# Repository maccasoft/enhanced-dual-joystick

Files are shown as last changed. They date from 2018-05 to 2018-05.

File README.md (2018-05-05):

## Enhanced Dual Joystick for RC2014

Add-on board designed for the [RC2014](http://rc2014.co.uk/) computer to provide an enhanced dual joystick port for games and other applications.

The board is based on a Z80 PIO that provide two 8-bit bi-direction parallel ports. Software can configure each port independently to use a standard Atari-compatibile joystick, a NES-compatible gamepad or any
other controller driven by digital I/O lines.

I/O ports can be configured with the on-board dip-switch.

### Schematics

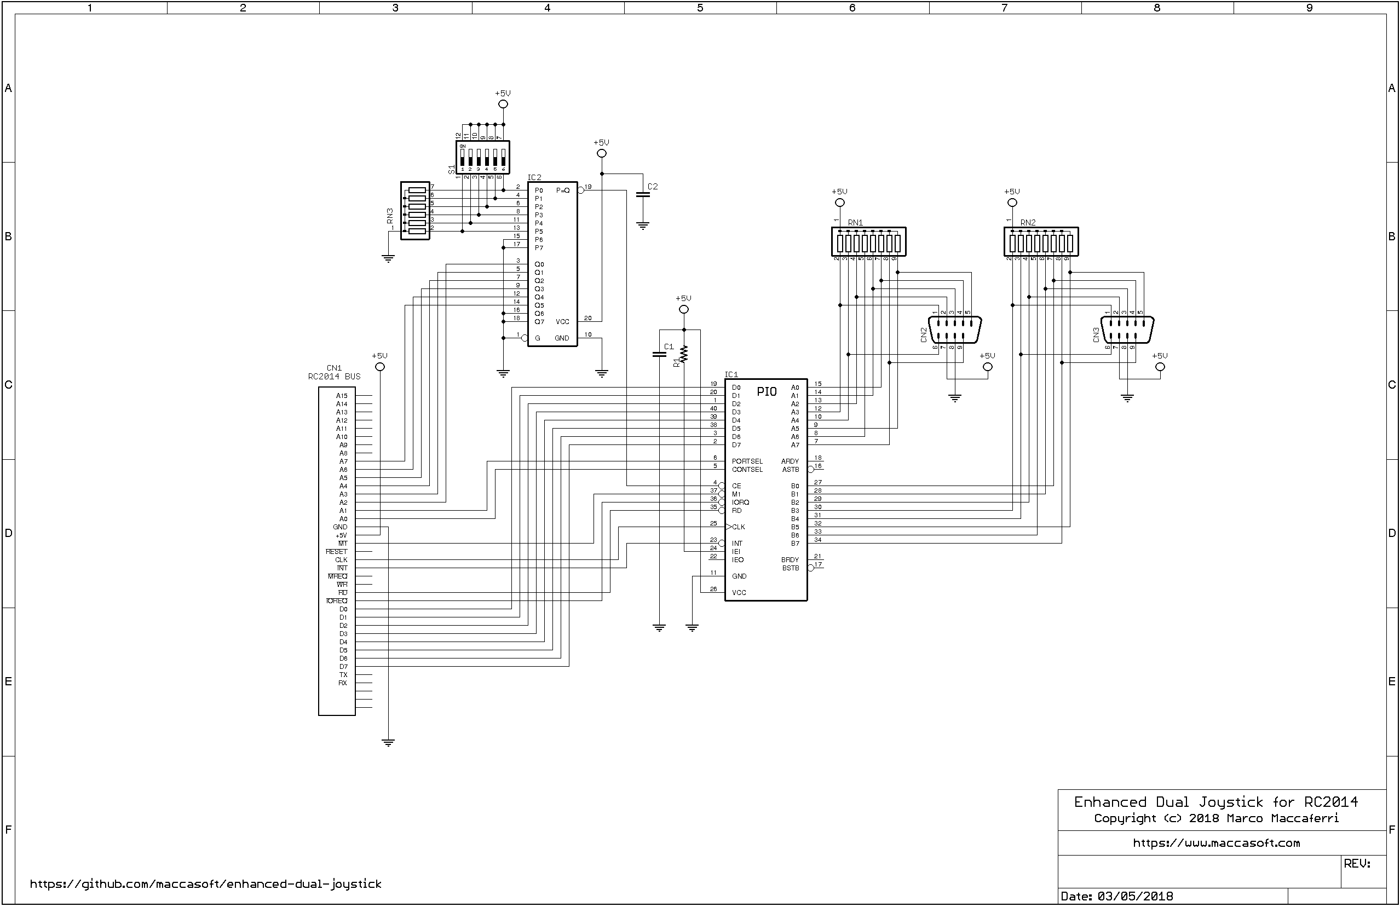
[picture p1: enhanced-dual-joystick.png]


| Parts List  | |
| --- | --- |
| R1 | 10.000 ohm 1/4 watt |
| RN1, RN2 | 10.000 ohm, 9-pin resistor network  |
| RN3 | 10.000 ohm, 7-pin resistor network  |
| C1, C2 | 100.000 pF polyester |
| IC1 | Z84C2010PEG |
| IC2 | CD74HCT688N |
| S1 | DIP-switch |
| CN1 | 40 pin male header, right angle |
| CN2, CN3 | DB9 male connector |

Additionally, a NES-compatible gamepad board is included for those who don't have access to an existing joystick.

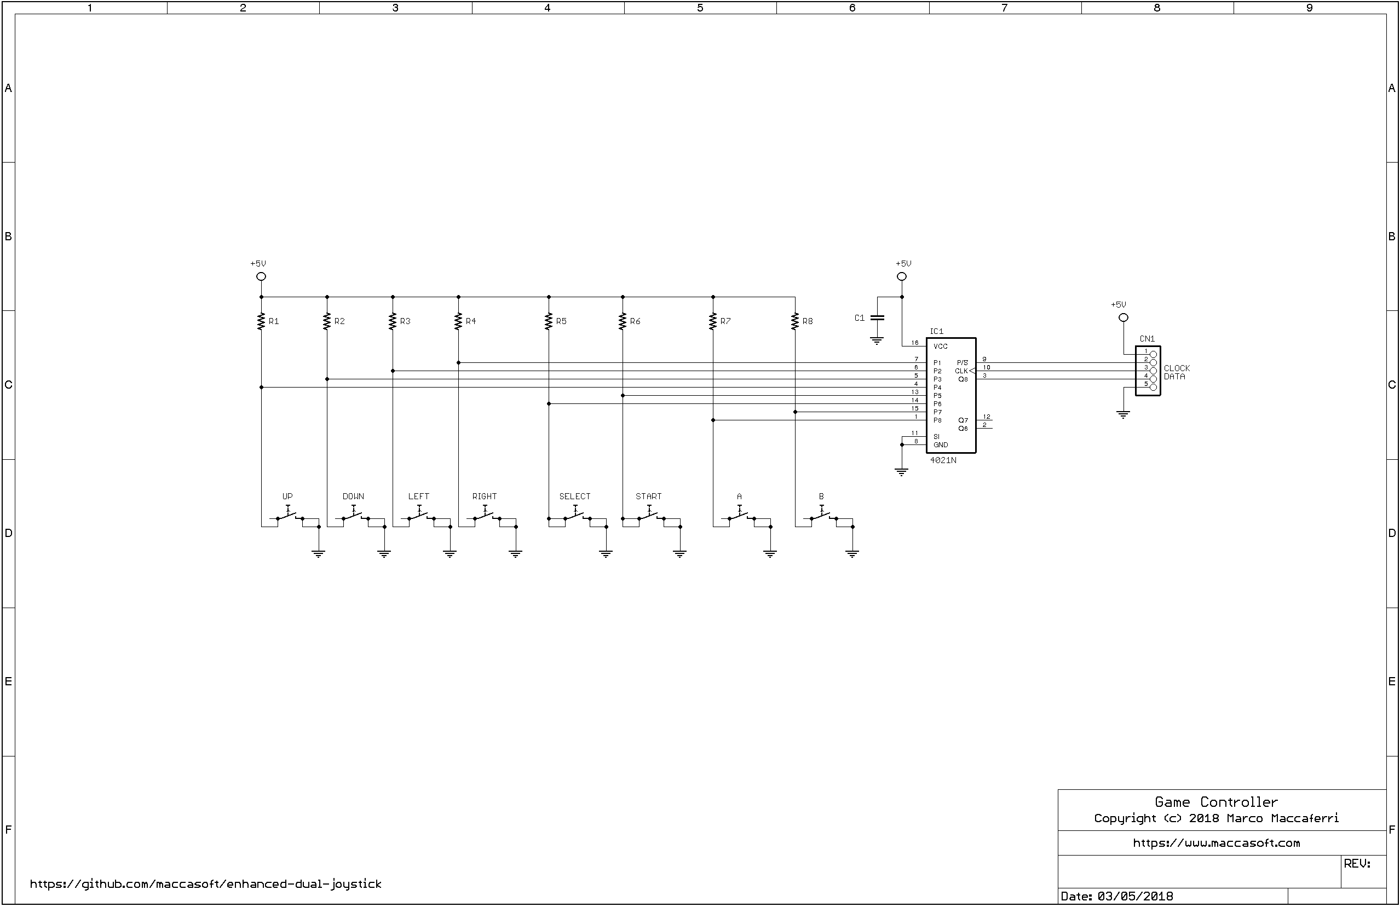
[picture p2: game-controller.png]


| Parts List | |
| --- | --- |
| R1-R8 | 10.000 ohm 1/4 watt |
| C1 | 100.000 pF polyester |
| IC1 | CD4021 |
| UP, DOWN, LEFT, RIGHT | 6x6 mm tact switches |
| SELECT, START, B, A | 6x6 mm tact switches |
| CN1 | 5-pin connector |

### Code Examples

The Z80 PIO must be initialized at startup by configuring both ports in control mode 3 followed by the pin direction settings appropriate for
the game controller type.

**Atari 2600 joystick.**

```
PIO_BASE    .EQU    70H

            ; initialize

            LD      A,0CFH              ; set port A mode 3 (control)
            OUT     (PIO_BASE+1),A
            LD      A,0FFH              ; all pins as input
            OUT     (PIO_BASE+1),A

            LD      A,0CFH              ; set port B mode 3 (control)
            OUT     (PIO_BASE+3),A
            LD      A,0FFH              ; all pins as input
            OUT     (PIO_BASE+3),A

            ; read joystick 1

            IN      A,(PIO_BASE)

            ; read joystick 2

            IN      A,(PIO_BASE+2)
```

**NES gamepad on Joystick 2.**

The code assumes that the gamepad is wired to the DB9 connector as follows: 4=data, 5=load, 6=clk.  

```
PIO_BASE    .EQU    70H

NES_LOAD    .EQU    20H
NES_CLK     .EQU    10H

            ; initialize

            LD      A,0CFH              ; set port A mode 3 (control)
            OUT     (PIO_BASE+1),A
            LD      A,0FFH              ; all pins as input
            OUT     (PIO_BASE+1),A

            LD      A,0CFH              ; set port B mode 3 (control)
            OUT     (PIO_BASE+3),A
            LD      A,~(NES_LOAD|NES_CLK)   ; clock and load pins as output, others as input
            OUT     (PIO_BASE+3),A
            LD      A,0
            OUT     (PIO_BASE+2),A

            ; read joystick 1

            IN      A,(PIO_BASE)

            ; read joystick 2

            LD      C,0

            LD      A,NES_LOAD          ; pulse load pin
            OUT     ((PIO_BASE+2),A
            LD      A,0
            OUT     (PIO_BASE+2),A

            LD      B,8
L1:         IN      A,(PIO_BASE+2)      ; read data from bit 0
            RRA
            RL      C

            LD      A,NES_CLOCK         ; pulse clock
            OUT     (PIO_BASE+2),A
            LD      A,0
            OUT     (PIO_BASE+2),A

            DJNZ    L1

            LD      A,C
```

### Boards

Boards are shared on OSHPark:

[Dual Joystick](https://oshpark.com/shared_projects/1jlMB1r2)  
[Game Controller](https://oshpark.com/shared_projects/LxgxoR9j)  

A [donation](https://www.paypal.me/maccasoft/5eur) to support this and future projects is always welcome!

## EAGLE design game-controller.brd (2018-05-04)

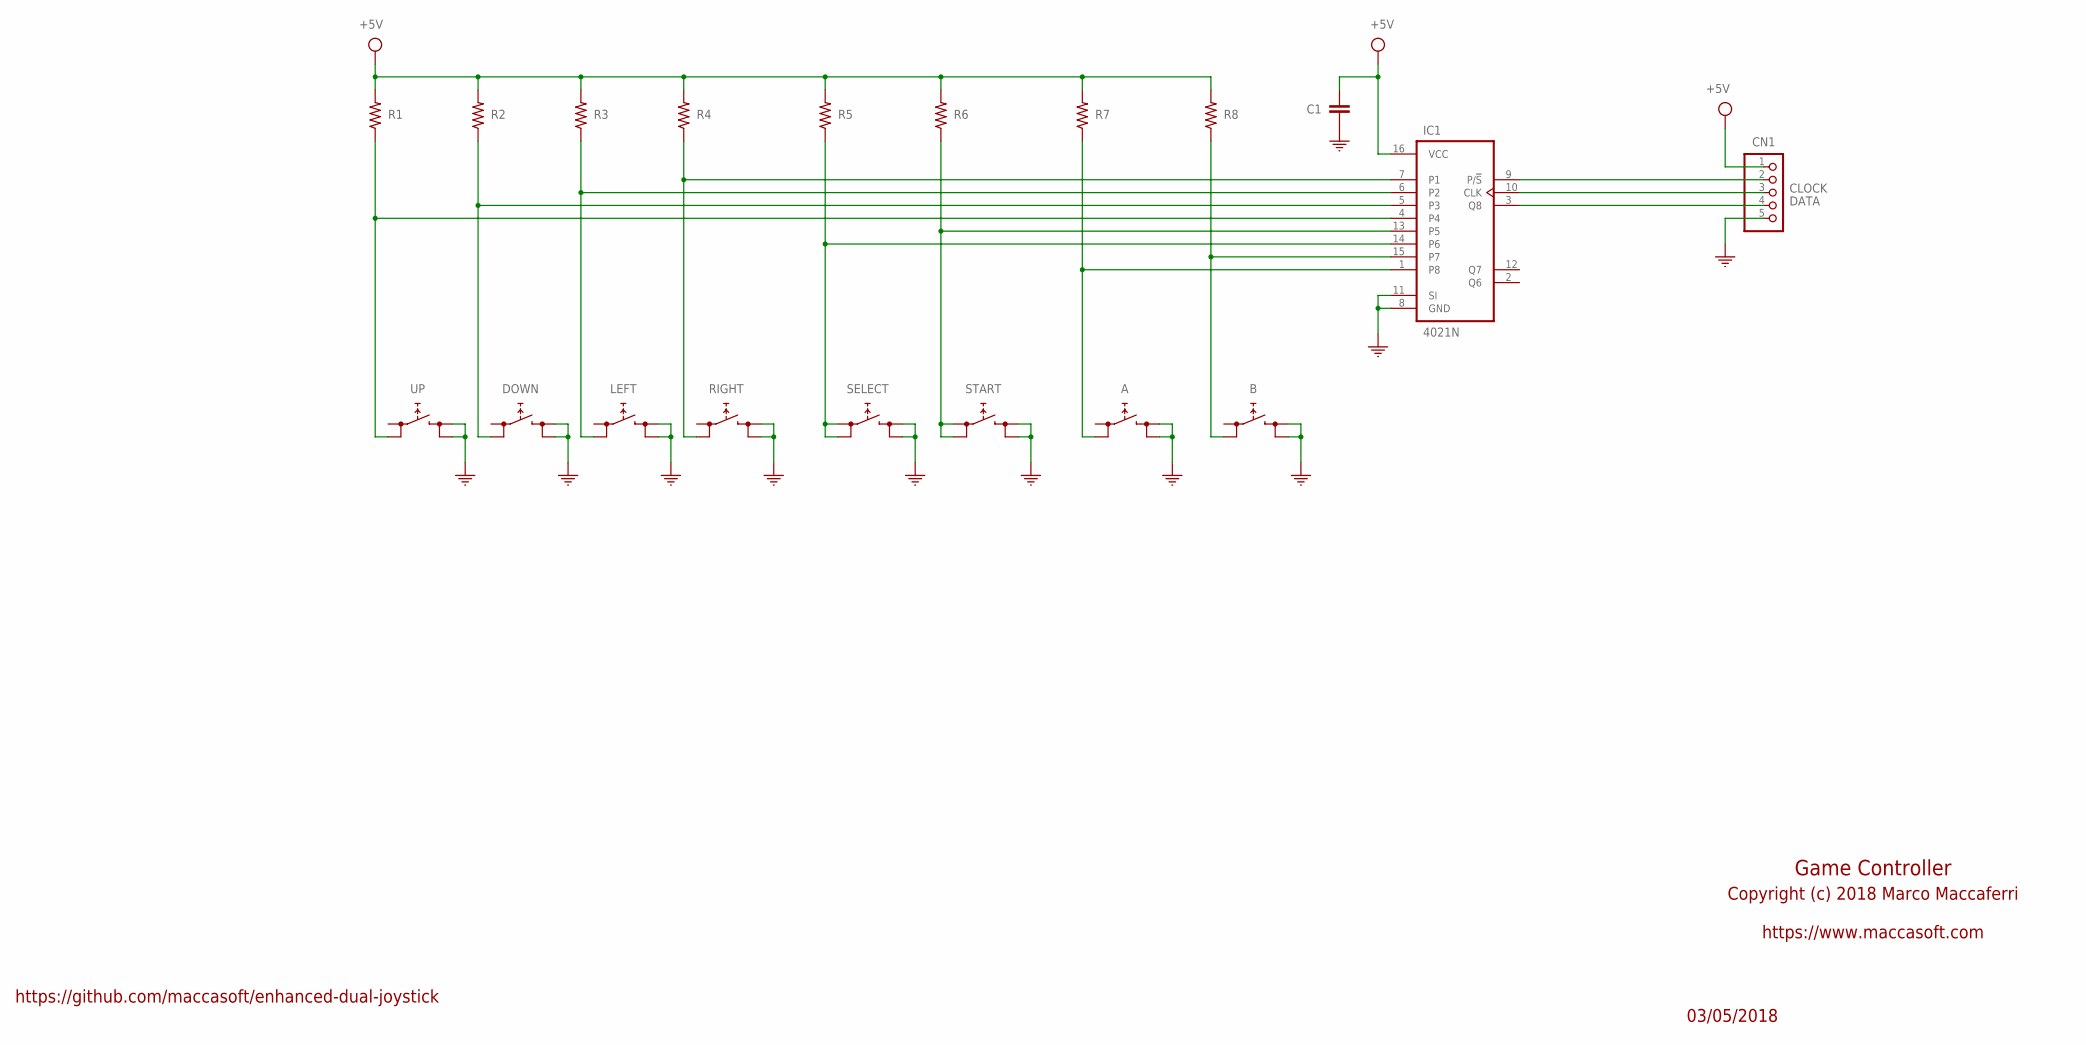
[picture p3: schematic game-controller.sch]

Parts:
A: FSM4JH; TL1105
B: FSM4JH; TL1105
C1: 100nF; C050-025X075; MPN R82EC3100AA70J
CN1: PINHD-1X5; 1X05
DOWN: FSM4JH; TL1105
IC1: 4021N; DIL16
LEFT: FSM4JH; TL1105
R1, R2, R3, R4, R5, R6, R7, R8: 10K; 0207/10; MPN CFR-25JB-52-10K
RIGHT: FSM4JH; TL1105
SELECT: FSM4JH; TL1105
START: FSM4JH; TL1105
UP: FSM4JH; TL1105

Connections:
+3.3V: C1.1, CN1.1, IC1.16 (VCC), R1.2, R2.2, R3.2, R4.2, R5.2, R6.2, R7.2, R8.2
A: A.3 (0), IC1.1 (P8), R7.1
B: B.3 (0), IC1.15 (P7), R8.1
CLOCK: CN1.3, IC1.10 (CLK)
DATA: CN1.4, IC1.3 (Q8)
DOWN: DOWN.3 (0), IC1.5 (P3), R2.1
GND: A.2 (1), A.4 (1), B.2 (1), B.4 (1), C1.2, CN1.5, DOWN.2 (1), DOWN.4 (1), IC1.8 (GND), IC1.11 (SI), LEFT.2 (1), LEFT.4 (1), RIGHT.2 (1), RIGHT.4 (1), SELECT.2 (1), SELECT.4 (1), START.2 (1), START.4 (1), UP.2 (1), UP.4 (1)
LEFT: IC1.6 (P2), LEFT.3 (0), R3.1
unnamed: CN1.2, IC1.9 (P/!S)
RIGHT: IC1.7 (P1), R4.1, RIGHT.3 (0)
SELECT: IC1.14 (P6), R5.1, SELECT.1 (0), SELECT.3 (0)
START: IC1.13 (P5), R6.1, START.1 (0), START.3 (0)
UP: IC1.4, R1.1, UP.3 (0)

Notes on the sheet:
Game Controller
03/05/2018
Copyright (c) 2018 Marco Maccaferri
https://github.com/maccasoft/enhanced-dual-joystick
https://www.maccasoft.com

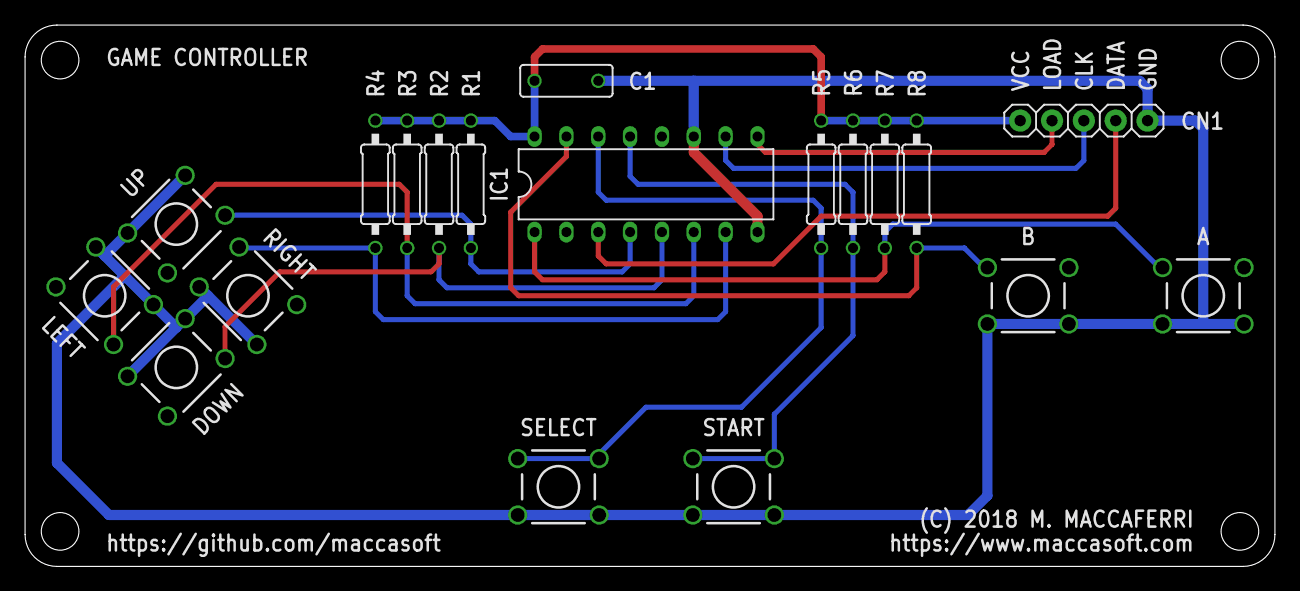
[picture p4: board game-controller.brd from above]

Board: 2 copper layers, 99.7 x 43.2 mm, 19 parts (0 on the bottom side), 13 nets.

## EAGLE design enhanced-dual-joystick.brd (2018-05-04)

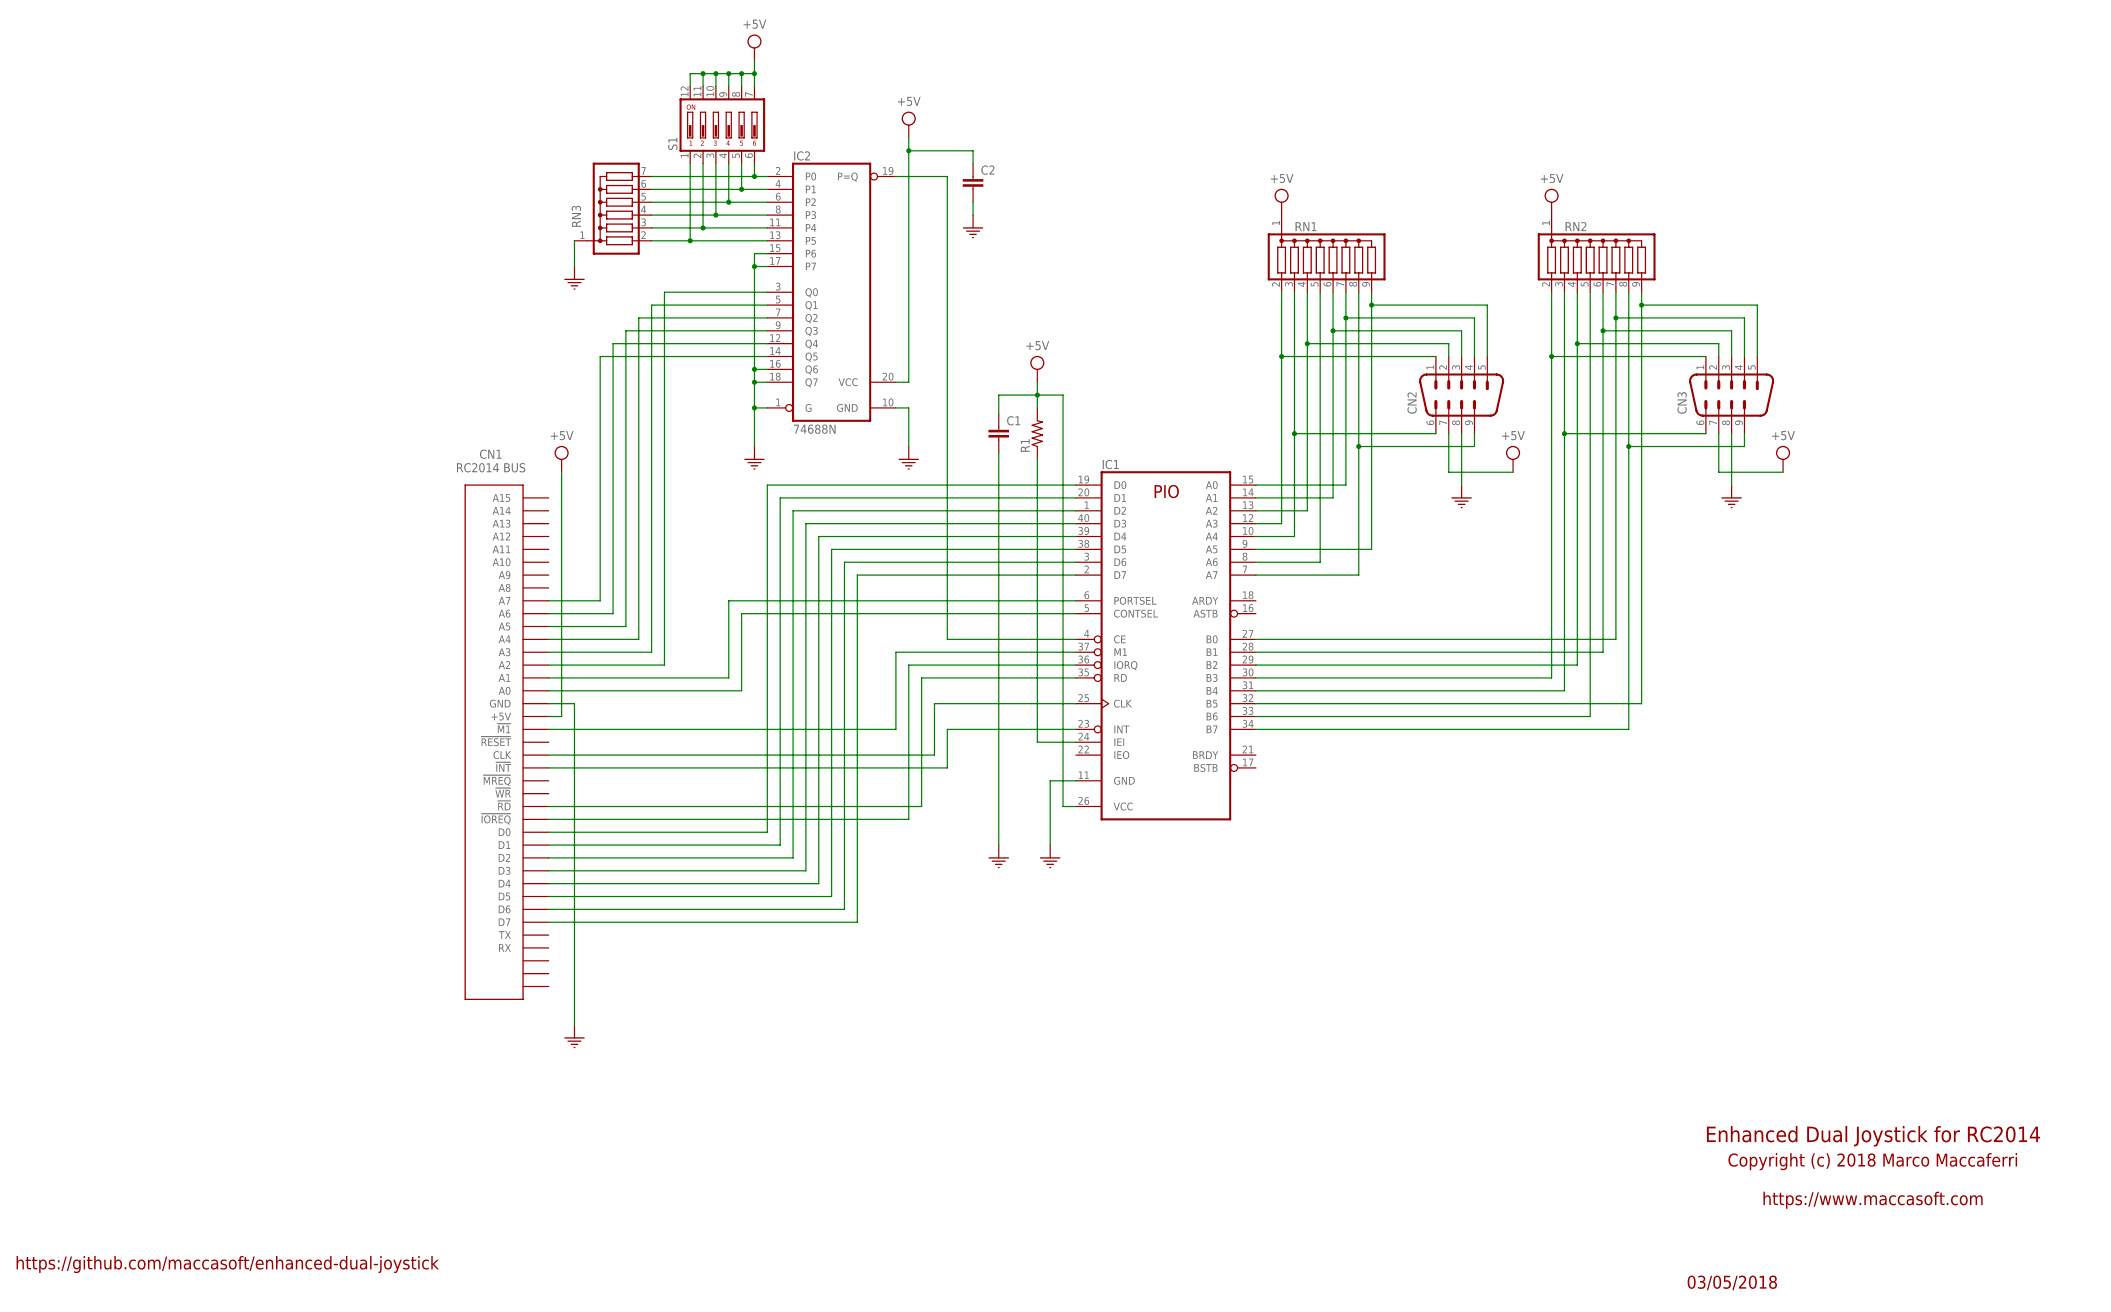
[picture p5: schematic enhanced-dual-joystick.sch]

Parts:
C1, C2: C-EU050-025X075; C050-025X075
CN1: RC2014BUS; MPN PRPC040SBAN-M71RC
CN2, CN3: M09H
IC1: Z80PIO; DIL40
IC2: 74688N; DIL20
R1: R-US_0207/10; 0207/10
RN1, RN2: G08R; SIL9
RN3: G06R; SIL7
S1: DIP06YL

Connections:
+5V: C1.1, C2.1, CN1.+5V, CN2.7, CN3.7, IC1.26 (VCC), IC2.20 (VCC), R1.2, RN1.1, RN2.1, S1.7, S1.8, S1.9, S1.10, S1.11, S1.12
GND: C1.2, C2.2, CN1.GND, CN2.8, CN3.8, IC1.11 (GND), IC2.1 (G), IC2.10 (GND), IC2.15 (P6), IC2.16 (Q6), IC2.17 (P7), IC2.18 (Q7), RN3.1
unnamed: CN2.1, IC1.12 (A3), RN1.2
unnamed: CN2.6, IC1.10 (A4), RN1.3
unnamed: CN2.2, IC1.13 (A2), RN1.4
unnamed: IC1.8 (A6), RN1.5
unnamed: CN2.3, IC1.14 (A1), RN1.6
unnamed: CN2.4, IC1.15 (A0), RN1.7
unnamed: CN2.9, IC1.7 (A7), RN1.8
unnamed: CN2.5, IC1.9 (A5), RN1.9
unnamed: IC2.2 (P0), RN3.7, S1.6
unnamed: IC2.4 (P1), RN3.6, S1.5
unnamed: IC2.6 (P2), RN3.5, S1.4
unnamed: IC2.8 (P3), RN3.4, S1.3
unnamed: IC2.11 (P4), RN3.3, S1.2
unnamed: IC2.13 (P5), RN3.2, S1.1
unnamed: CN1.A7, IC2.14 (Q5)
unnamed: CN1.A6, IC2.12 (Q4)
unnamed: CN1.D7, IC1.2 (D7)
unnamed: CN1.D6, IC1.3 (D6)
unnamed: CN1.D5, IC1.38 (D5)
unnamed: CN1.D4, IC1.39 (D4)
unnamed: CN1.D3, IC1.40 (D3)
unnamed: CN1.D2, IC1.1 (D2)
unnamed: CN1.D1, IC1.20 (D1)
unnamed: CN1.D0, IC1.19 (D0)
unnamed: CN1.!IOREQ!, IC1.36 (IORQ)
unnamed: CN1.!RD!, IC1.35 (RD)
unnamed: CN1.!M1!, IC1.37 (M1)
unnamed: CN1.CLK, IC1.25 (CLK)
unnamed: CN1.!INT!, IC1.23 (INT)
unnamed: CN1.A5, IC2.9 (Q3)
unnamed: CN1.A4, IC2.7 (Q2)
unnamed: CN1.A3, IC2.5 (Q1)
unnamed: CN1.A2, IC2.3 (Q0)
unnamed: IC1.4 (CE), IC2.19 (P=Q)
unnamed: CN1.A1, IC1.6 (PORTSEL)
unnamed: CN1.A0, IC1.5 (CONTSEL)
unnamed: IC1.33 (B6), RN2.5
unnamed: IC1.24 (IEI), R1.1
unnamed: CN3.1, IC1.30 (B3), RN2.2
unnamed: CN3.6, IC1.31 (B4), RN2.3
unnamed: CN3.2, IC1.29 (B2), RN2.4
unnamed: CN3.3, IC1.28 (B1), RN2.6
unnamed: CN3.4, IC1.27 (B0), RN2.7
unnamed: CN3.9, IC1.34 (B7), RN2.8
unnamed: CN3.5, IC1.32 (B5), RN2.9

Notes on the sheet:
CN1 RC2014 BUS
Enhanced Dual Joystick for RC2014
03/05/2018
Copyright (c) 2018 Marco Maccaferri
https://github.com/maccasoft/enhanced-dual-joystick
https://www.maccasoft.com

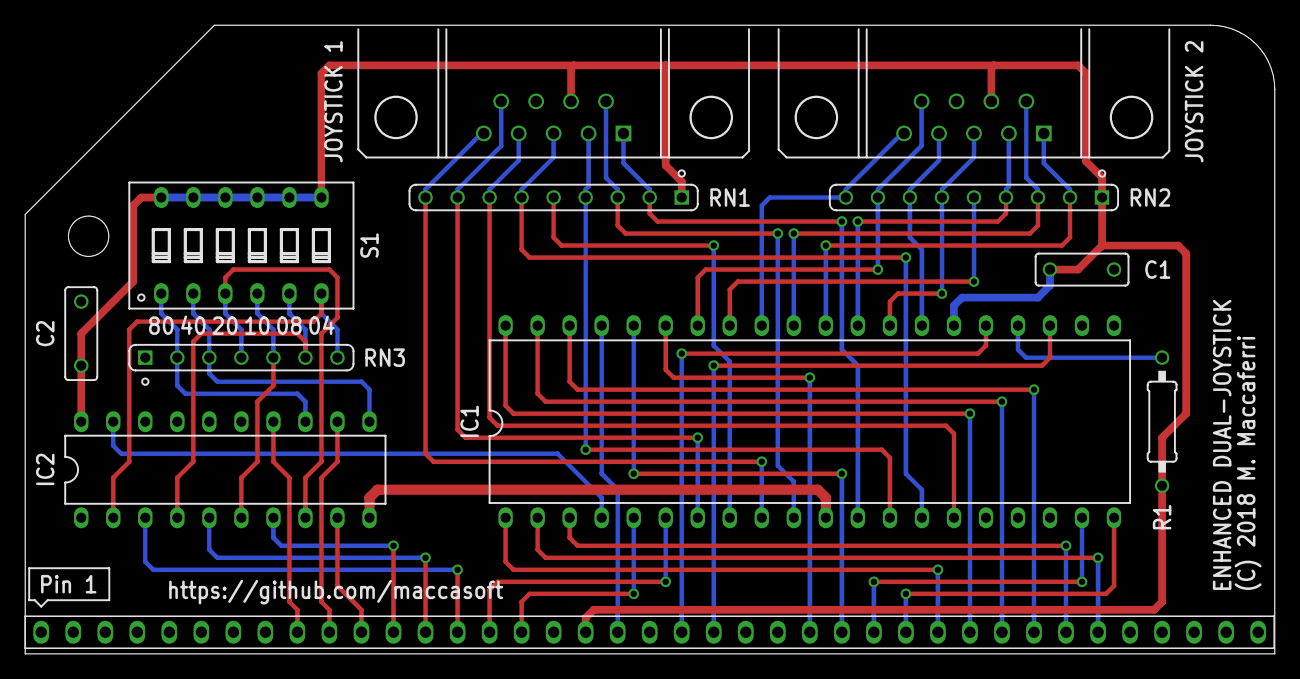
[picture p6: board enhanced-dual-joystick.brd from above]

Board: 2 copper layers, 99.1 x 49.9 mm, 12 parts (0 on the bottom side), 47 nets.

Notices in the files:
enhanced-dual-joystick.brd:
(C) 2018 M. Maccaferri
